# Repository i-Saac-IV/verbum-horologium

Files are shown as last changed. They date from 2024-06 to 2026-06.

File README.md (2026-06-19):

# Verbum Horologium
A digital clock that displays time in an analog fashion.

# Table of Contents
- [Features](#features)
- [Fixes and Updates](#fixes-and-updates)
- [Pictures and Video](#pictures-and-video)
- [Hardware and Setup](#hardware-and-setup)
  - [Laser Cut Housing](#laser-cut-housing)
  - [3D Printed Framing](#3d-printed-framing)
  - [Printed Circuit Board](#printed-circuit-board)
  - [Code](#code)
    - [Dependencies](#dependencies)
- [Copyright and Licensing](#copyright-and-licensing)
- [Contact](#contact)

# Features
- Invisible capacitive touch buttons for user input.
- Automatic brightness control via ambient light sensor.
- Night mode, turning off the display when the room is dark.
- Serial passthrough for updating the real-time clock (RTC).

# Fixes and Updates
> [!IMPORTANT]
> This project is currently under development undergoing a major code refactor. Please bear with me while I work on improving functionality.

# Pictures and Video
<table align="center">
  <tr>
    <td align="center">
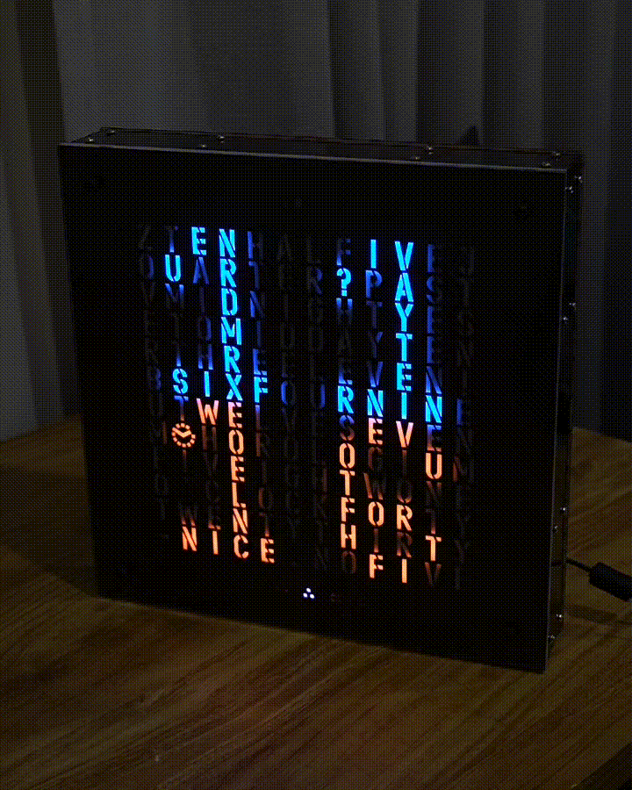
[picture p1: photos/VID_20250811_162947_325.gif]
      <br>
      <b>Demo</b>
    </td>
  </tr>
</table>
<table align="center">
  <tr>
    <td align="center">
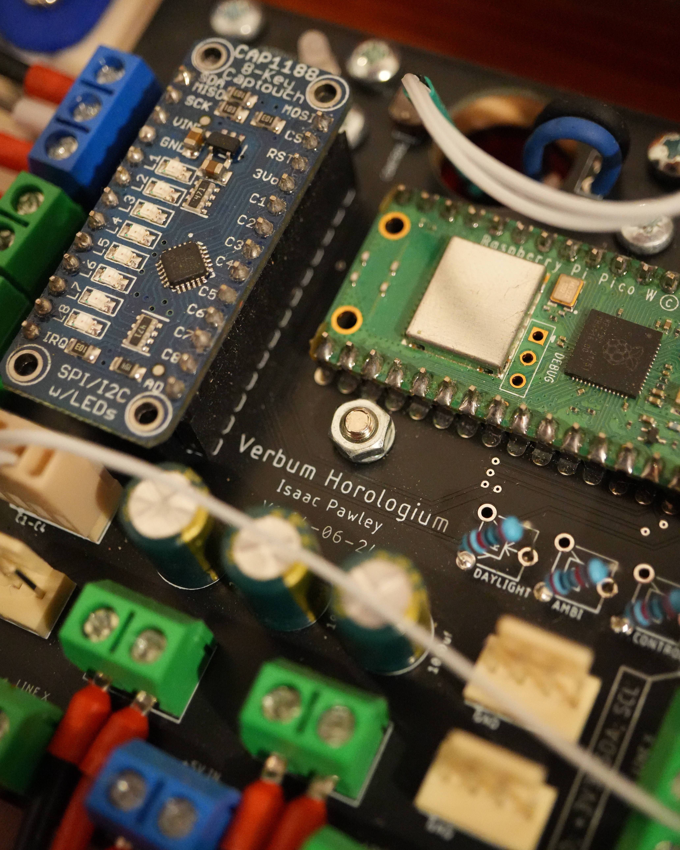
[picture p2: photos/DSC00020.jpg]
      <br>
      <b>Main control board</b>
    </td>
    <td align="center">
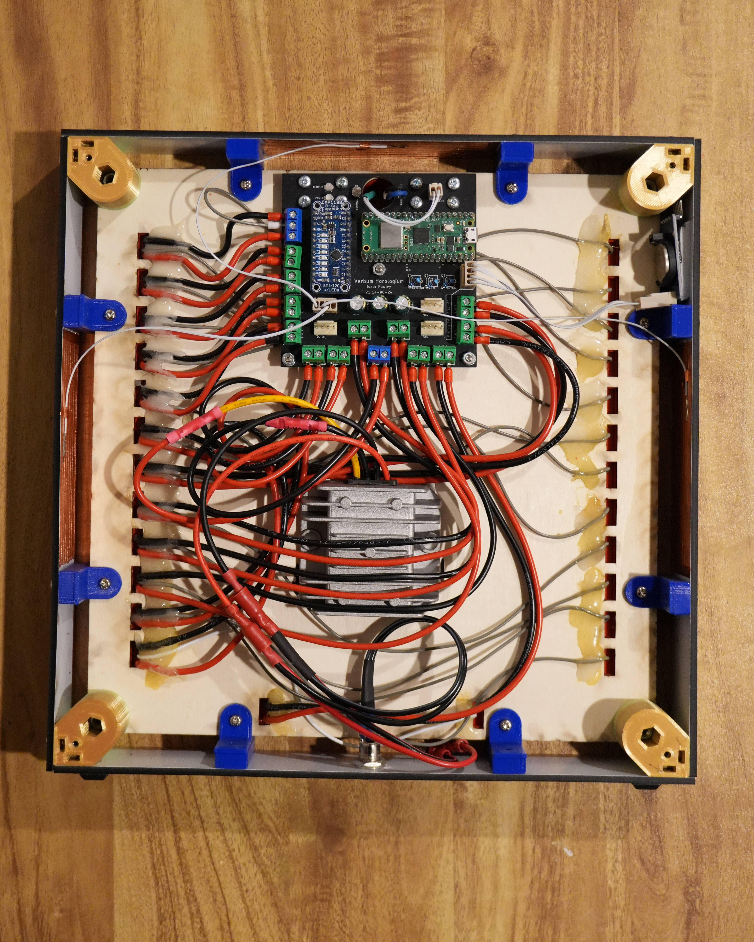
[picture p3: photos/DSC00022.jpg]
      <br>
      <b>Internal wiring</b>
    </td>
    <td align="center">
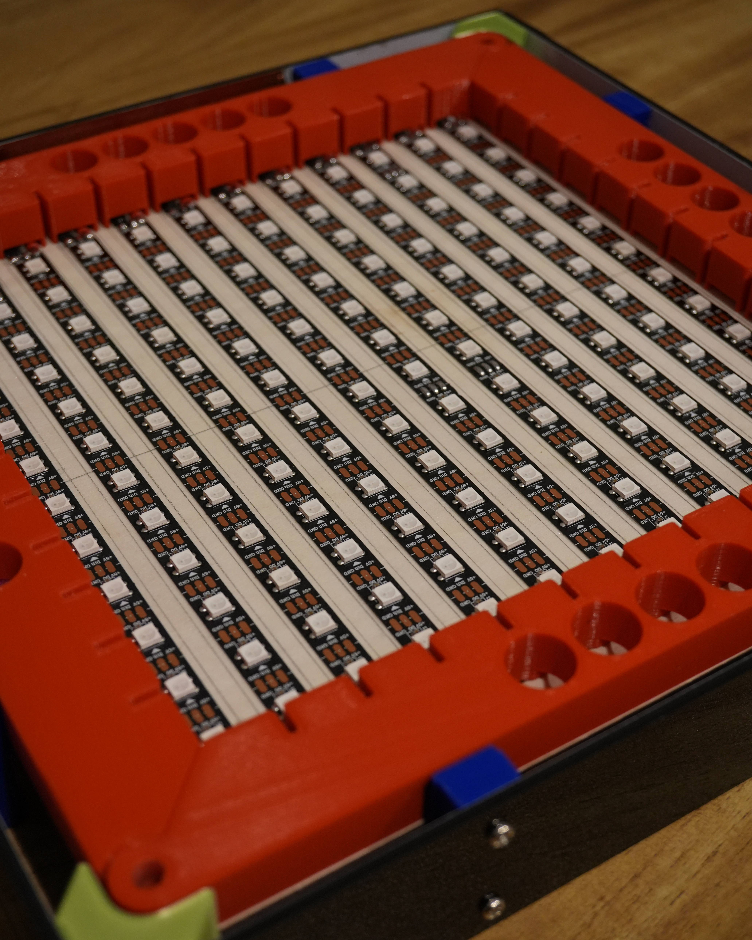
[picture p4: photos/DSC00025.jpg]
      <br>
      <b>LED matrix array</b>
    </td>
  </tr>
</table>

# Hardware and Setup

## Laser Cut Housing
All laser cutting files can be found [here](/assets/laser/).

Please insure that:
- The [LED diffuser](/assets/laser/diffusion_white-acrylic.svg) is cut out of white acrylic.
- The [clock face](/assets/laser/clock-face_black-polypropylene.svg) is cut out of a thin and opaque material.
- The [bottom](/assets/laser/bottom-side_black-acrylic.svg) and [sides](/assets/laser/side_black-acrylic.svg) are cut out of an opaque material.

Doing so will ensure the clock performs at its best.

## 3D Printed Framing
The 3D printed components will not be visible from the front of the clock, so do not worry about surface finish or colour. However, several of the prints will have to be paused throughout the print to insert embedded fasteners.

## Printed Circuit Board
The gerber files for PCB manufacturing can be found [here](/assets/pcb/mainboard_v1_14-06-24.zip).

## Code
### Dependencies
This project requires the following external Arduino libraries, please ensure that they are installed:
- [FastLED (v3.10.3)](https://github.com/FastLED/FastLED/tree/3.10.3)
- [RTClib by Adafruit (v2.1.4)](https://github.com/adafruit/RTClib/tree/2.1.4)
- [CAP1188 Library by Adafruit (v1.1.3)](https://github.com/adafruit/Adafruit_CAP1188_Library/tree/1.1.3)

For programming of the Raspberry Pi Pico W via the Arduino IDE I've included the board library I used here:
- [Arduino Pico by Earle F. Philhower, III (v5.6.0)](https://github.com/earlephilhower/arduino-pico/tree/5.6.0)

Open the Arduino IDE, install the code and board libraries mentioned above, plug in your mainboard, and upload the code.

# Copyright and Licensing
See [license](LICENSE) for in depth info.

This project uses the following third-party libraries:

- FastLED (MIT License)
- RTClib (MIT License)
- Adafruit CAP1188 (BSD License)
- Arduino Pico (LGPL License)

Copyright and license terms belong to their respective authors.

Contact me if anything here is incorrect.

# Contact
If you'd like to get in touch, feel free to reach out!
<p>
  <a href="https://github.com/i-Saac-IV">
    
  </a>
  <a href="https://www.linkedin.com/in/isaac-pawley/">
    
  </a>
  <a href="https://www.instagram.com/i.saac.0100/">
    
  </a>
</p>

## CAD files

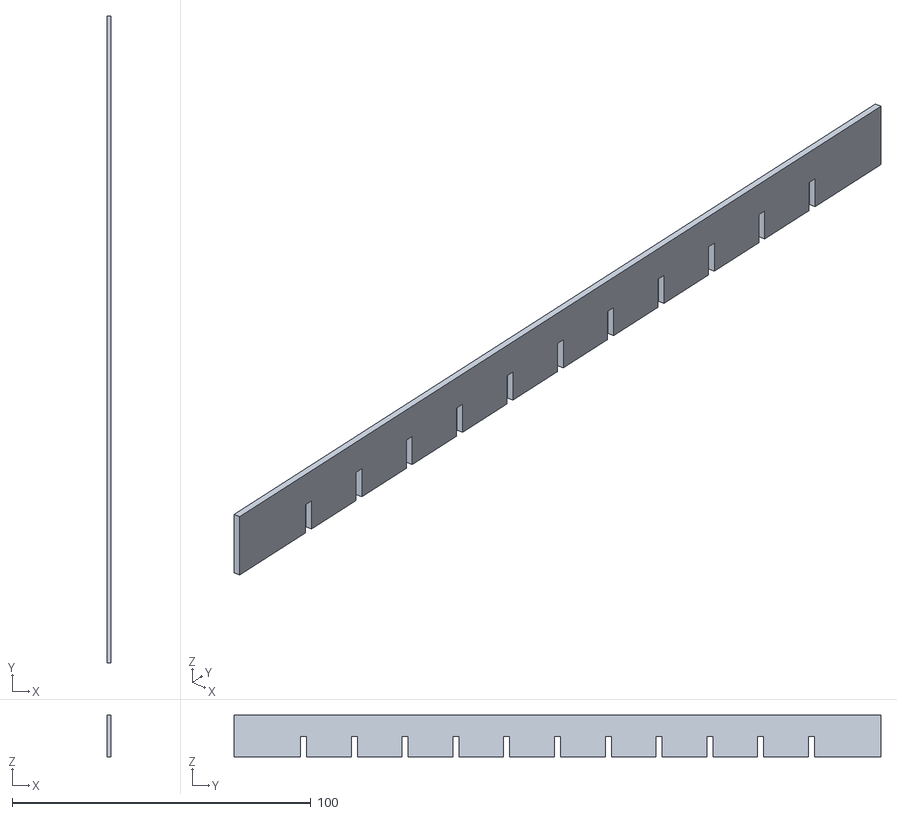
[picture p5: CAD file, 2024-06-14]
assets/3d/grid-short_11x.stl
1.50 x 216.5 x 14.0

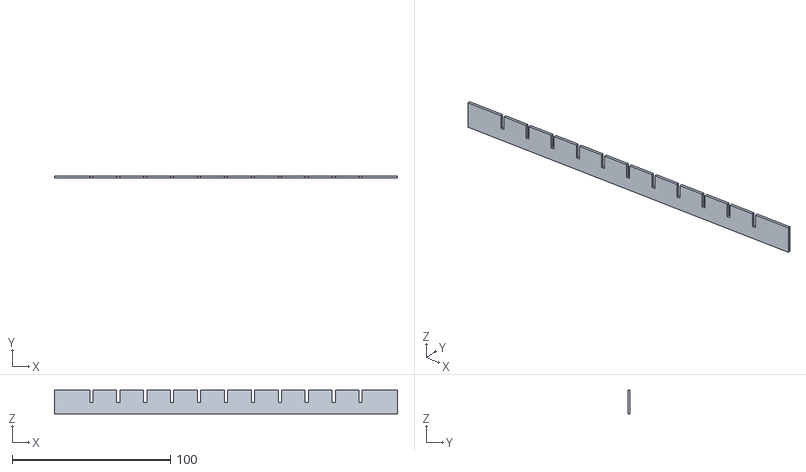
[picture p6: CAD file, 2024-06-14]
assets/3d/grid-tall_11x.stl
216.5 x 1.50 x 15.0

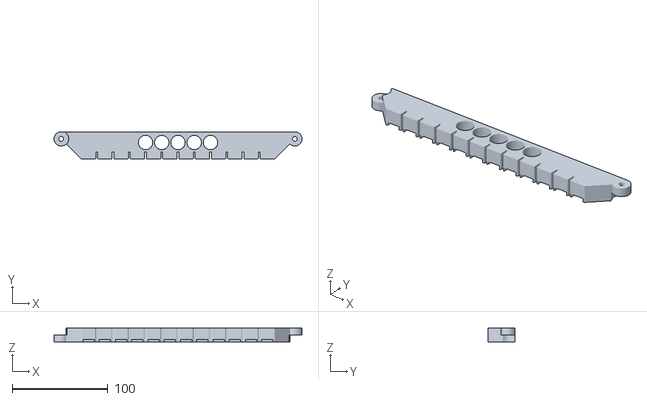
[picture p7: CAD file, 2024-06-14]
assets/3d/grid-frame_4x.stl
259.4 x 28.8 x 15.0

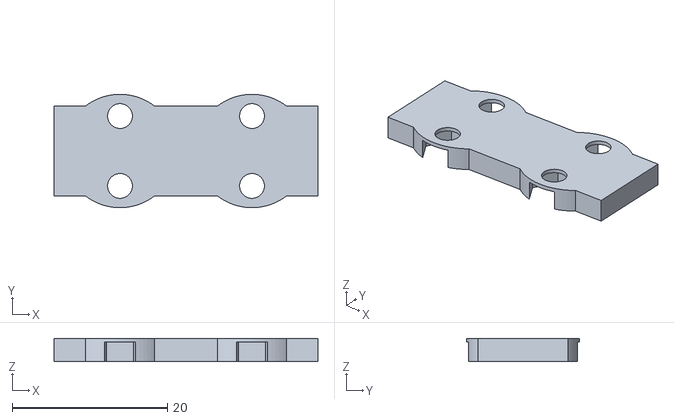
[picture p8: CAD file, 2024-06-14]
assets/3d/bolt-holder_2x.stl
34.0 x 14.6 x 3.00

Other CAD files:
assets/verbum-horologium.f3d

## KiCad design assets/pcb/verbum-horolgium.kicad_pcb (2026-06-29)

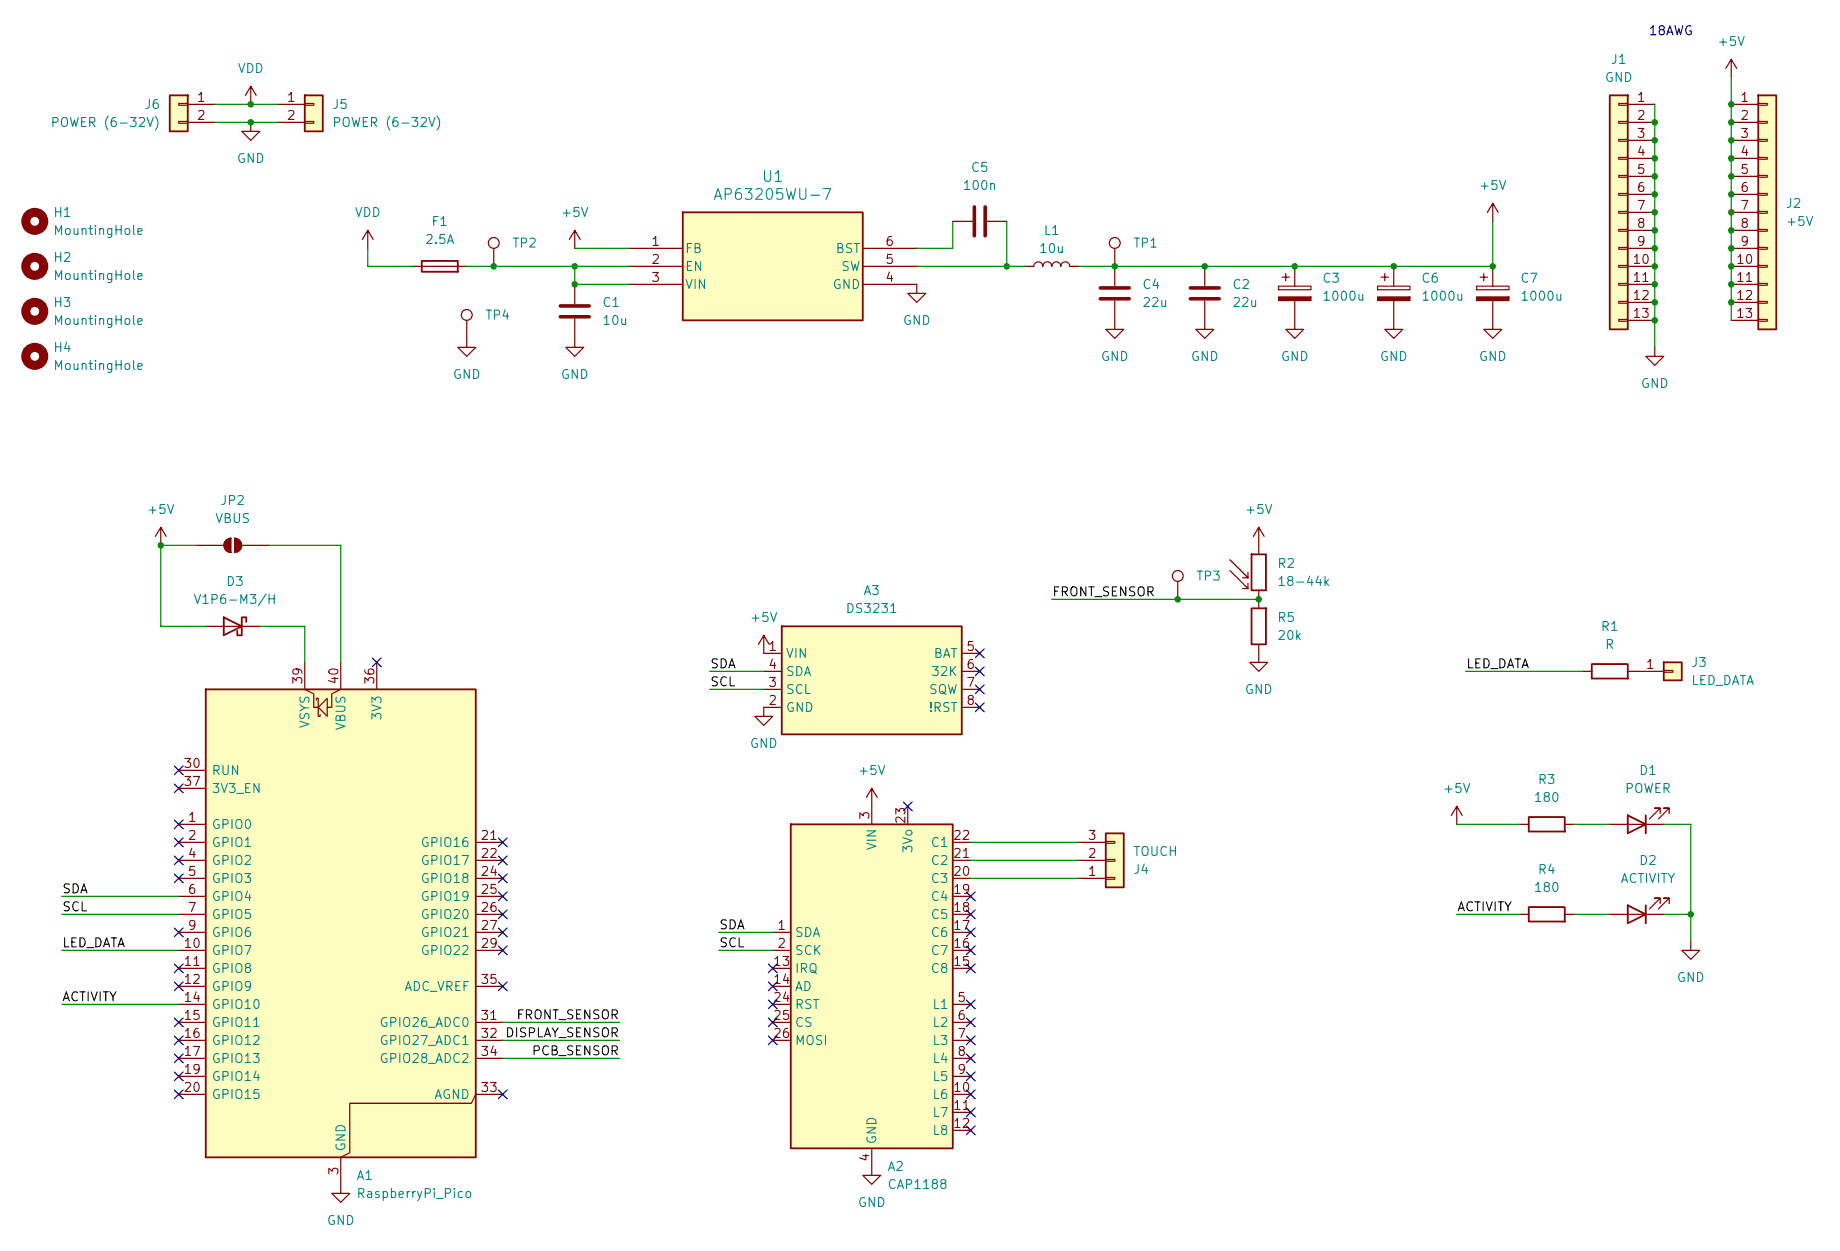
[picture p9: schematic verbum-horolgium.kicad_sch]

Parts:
A1: RaspberryPi_Pico; RaspberryPi_Pico_Common_Unspecified
A2: CAP1188; CAP1188-breakout
A3: DS3231; DS3231-breakout
C1: 10u; C_1210_3225Metric
C2, C4: 22u; C_1206_3216Metric
C3, C6, C7: 1000u; CP_Elec_10x10
C5: 100n; C_0805_2012Metric
D1: POWER; LED_1206_3216Metric
D2: ACTIVITY; LED_1206_3216Metric
D3: V1P6-M3/H; D_MicroSMP_LargeCathode
F1: 2.5A; Fuse_0603_1608Metric
H1, H2, H3, H4: MountingHole; MountingHole_3.2mm_M3
J1: GND; SolderWire-1.5sqmm_1x13_P5mm_D1.7mm_OD3mm_Relief
J2: +5V; SolderWire-1.5sqmm_1x13_P5mm_D1.7mm_OD3mm_Relief
J3: LED_DATA; SolderWire-1.5sqmm_1x1_P5mm_D1.7mm_OD3mm_Relief
J4: TOUCH; SolderWire-1.5sqmm_1x3_P5mm_D1.7mm_OD3mm_Relief
J5, J6: POWER (6-32V); SolderWire-1.5sqmm_1x2_P5mm_D1.7mm_OD3mm_Relief
JP2: VBUS; SolderJumper-2_P1.3mm_Open_TrianglePad1.0x1.5mm
L1: 10u; L_Wurth_WE-TPC-1038
R1: R; R_Axial_DIN0207_L6.3mm_D2.5mm_P7.62mm_Horizontal
R2: 18-44k; SolderWire-1.5sqmm_1x2_P5mm_D1.7mm_OD3mm_Relief
R3, R4: 180; R_0603_1608Metric
R5: 20k; R_Axial_DIN0207_L6.3mm_D2.5mm_P7.62mm_Horizontal
TP1, TP2, TP3, TP4: PinHeader_1x01_P1.00mm_Vertical
U1: AP63205WU-7; SOIC_05WU-7_DIO

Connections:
+5V: A2.3 (VIN), A3.1 (VIN), C2.1, C3.1, C4.1, C6.1, C7.1, D3.2 (A), J2.1, J2.2, J2.3, J2.4, J2.5, J2.6, J2.7, J2.8, J2.9, J2.10, J2.11, J2.12, J2.13, JP2.2 (B), L1.2, R2.1, R3.1, TP1.1 (1_1), U1.1 (FB)
/ACTIVITY: A1.14 (GPIO10), R4.1
/DISPLAY_SENSOR: A1.32 (GPIO27_ADC1)
/FRONT_SENSOR: A1.31 (GPIO26_ADC0), R2.2, R5.2, TP3.1 (1_1)
/LED_DATA: A1.10 (GPIO7), R1.1
/PCB_SENSOR: A1.34 (GPIO28_ADC2)
/SCL: A1.7 (GPIO5), A2.2 (SCK), A3.3 (SCL)
/SDA: A1.6 (GPIO4), A2.1 (SDA), A3.4 (SDA)
GND: A1.3 (GND), A1.8 (GND), A1.13 (GND), A1.18 (GND), A1.23 (GND), A1.28 (GND), A1.38 (GND), A2.4 (GND), A3.2 (GND), C1.2, C2.2, C3.2, C4.2, C6.2, C7.2, D1.1 (K), D2.1 (K), J1.1, J1.2, J1.3, J1.4, J1.5, J1.6, J1.7, J1.8, J1.9, J1.10, J1.11, J1.12, J1.13, J5.2, J6.2, R5.1, TP4.1 (1_1), U1.4 (GND)
unnamed: A1.40 (VBUS), JP2.1 (A)
unnamed: A1.39 (VSYS), D3.1 (K)
unnamed: A2.22 (C1), J4.3
unnamed: A2.21 (C2), J4.2
unnamed: A2.20 (C3), J4.1
unnamed: D1.2 (A), R3.2
unnamed: D2.2 (A), R4.2
unnamed: J3.1 (Pin_1_1), R1.2
unnamed: C5.1, U1.6 (BST)
unnamed: C1.1, F1.2, TP2.1 (1_1), U1.2 (EN), U1.3 (VIN)
unnamed: C5.2, L1.1, U1.5 (SW)
VDD: F1.1, J5.1, J6.1

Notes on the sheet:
18AWG

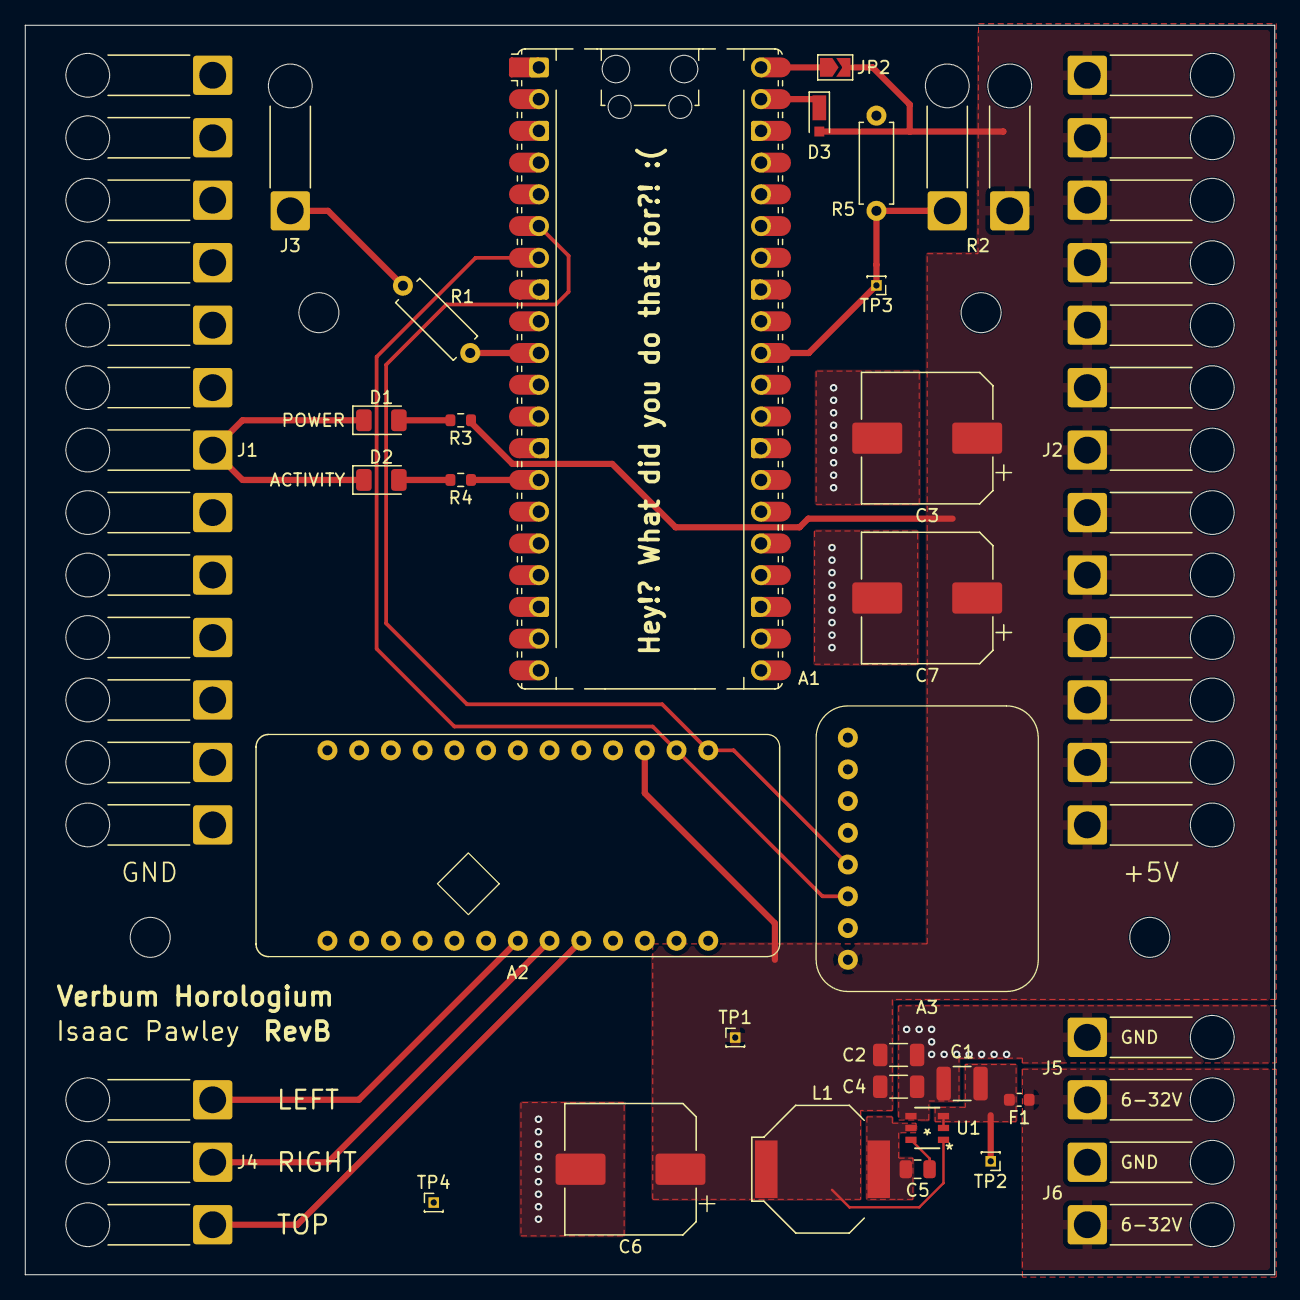
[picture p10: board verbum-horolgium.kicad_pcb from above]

Board: 2 copper layers, 100.0 x 100.0 mm, 36 parts (1 on the bottom side), 19 nets.

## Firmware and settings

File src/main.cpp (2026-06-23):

/*

File:   main.cpp
Author: Isaac Pawley
Date:   28-04-2026
Repo:   https://github.com/i-Saac-IV/verbum-horologium

*/

#include <Arduino.h>
#include "task_scheduler.h"
#include "startup_animation.h"

void setup() {
    task_scheduler_init();
    task_scheduler_initAllTasks();

    startup_animation();
}

void loop() {
    task_scheduler_executeEnabledTasks();
    task_scheduler_enableTask(TRIGGER_HEARTBEAT);
}

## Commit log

2024-06-14 adding all current physical files
    [bolt-holder_2x.stl, grid-frame_4x.stl, grid-short_11x.stl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]
2024-08-13 final commit??
    [verbum-horologium.f3d]
2026-04-29 fix: started code refector
    [main.cpp]
2026-04-29 fix: mircogl draws number bitmaps
    [main.cpp]
2026-05-01 feat: touch buttons working
2026-05-03 feat: added scaling for brightness sensors
2026-05-05 fix: matrix dimming works as does config
    [main.cpp]
2026-05-18 fix: added word clock into main code
    [main.cpp]
2026-05-20 fix: all tasks running via task scheduler
    [main.cpp]
2026-05-20 chore: clockface changes on long presses of side buttons
2026-05-21 chore: minor change to how messages are printed
2026-06-19 fix: added external access to led_matrix
2026-06-21 chore: updated gitignore for new pcb files
2026-06-21 chore: deleted old pcb files
    [mainboard.brd, mainboard.sch]
2026-06-21 chore: added new pcb files
    [verbum-horolgium.kicad_pcb, verbum-horolgium.kicad_sch]
2026-06-23 fix: heartbeat now beats regulary
    [main.cpp]
2026-06-23 feat: added version printing
2026-06-24 chore: added footprints and symbols
2026-06-24 chore: basic schematic complete
    [verbum-horolgium.kicad_sch]
2026-06-29 chore: pcb layout complete
    [verbum-horolgium.kicad_pcb, verbum-horolgium.kicad_sch]
2026-06-29 chore: added text to front silkscreen
    [verbum-horolgium.kicad_pcb, verbum-horolgium.kicad_sch]
2026-06-29 fix: added mounting holes
    [verbum-horolgium.kicad_pcb, verbum-horolgium.kicad_sch]
2026-06-29 chore: exported rev b gerber files
